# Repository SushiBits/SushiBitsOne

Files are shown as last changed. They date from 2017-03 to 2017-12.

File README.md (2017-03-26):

# SushiBits One

ARM Cortex-M in Arduino form factor, and consumes very little power.

## Introduction & Goal

This is one of my "design challenges" to myself:

*   Arduino-compatible form factor,
*   Take an 48-pin STM32 microcontroller (since STM32F103CBT6 are that cheap,)
*   Bring all I/O pins out somewhere, be it the connectors, JTAG or USB,
*   No two pins can be shorted together,
*   Use only switch-mode power supply,
*   Two layer PCB only,
*   Single side load.

## Main components

*   STM32 microcontroller in LQFP-48 package. I have tested the following:
    *   STM32F072C8T6 (Cortex-M0 @48MHz)
    *   STM32F103CBT6 (Cortex-M3 @72MHz)
    *   STM32L151CCT6 (Cortex-M3 @32MHz, ULP)
    *   STM32F303CCT6 (Cortex-M4F @72MHz)
    *   STM32F373CCT6 (Cortex-M4F @72MHz)
*   WCH CH340B: USB to UART adapter.
*   TI TPS562200: VIN to 5V buck converter.
*   TI LM3671-3.3: 5V to 3.3V buck converter.

## License

This is [open source hardware](http://www.oshwa.org/), licensed under the
[3-clause BSD license](LICENSE.md).

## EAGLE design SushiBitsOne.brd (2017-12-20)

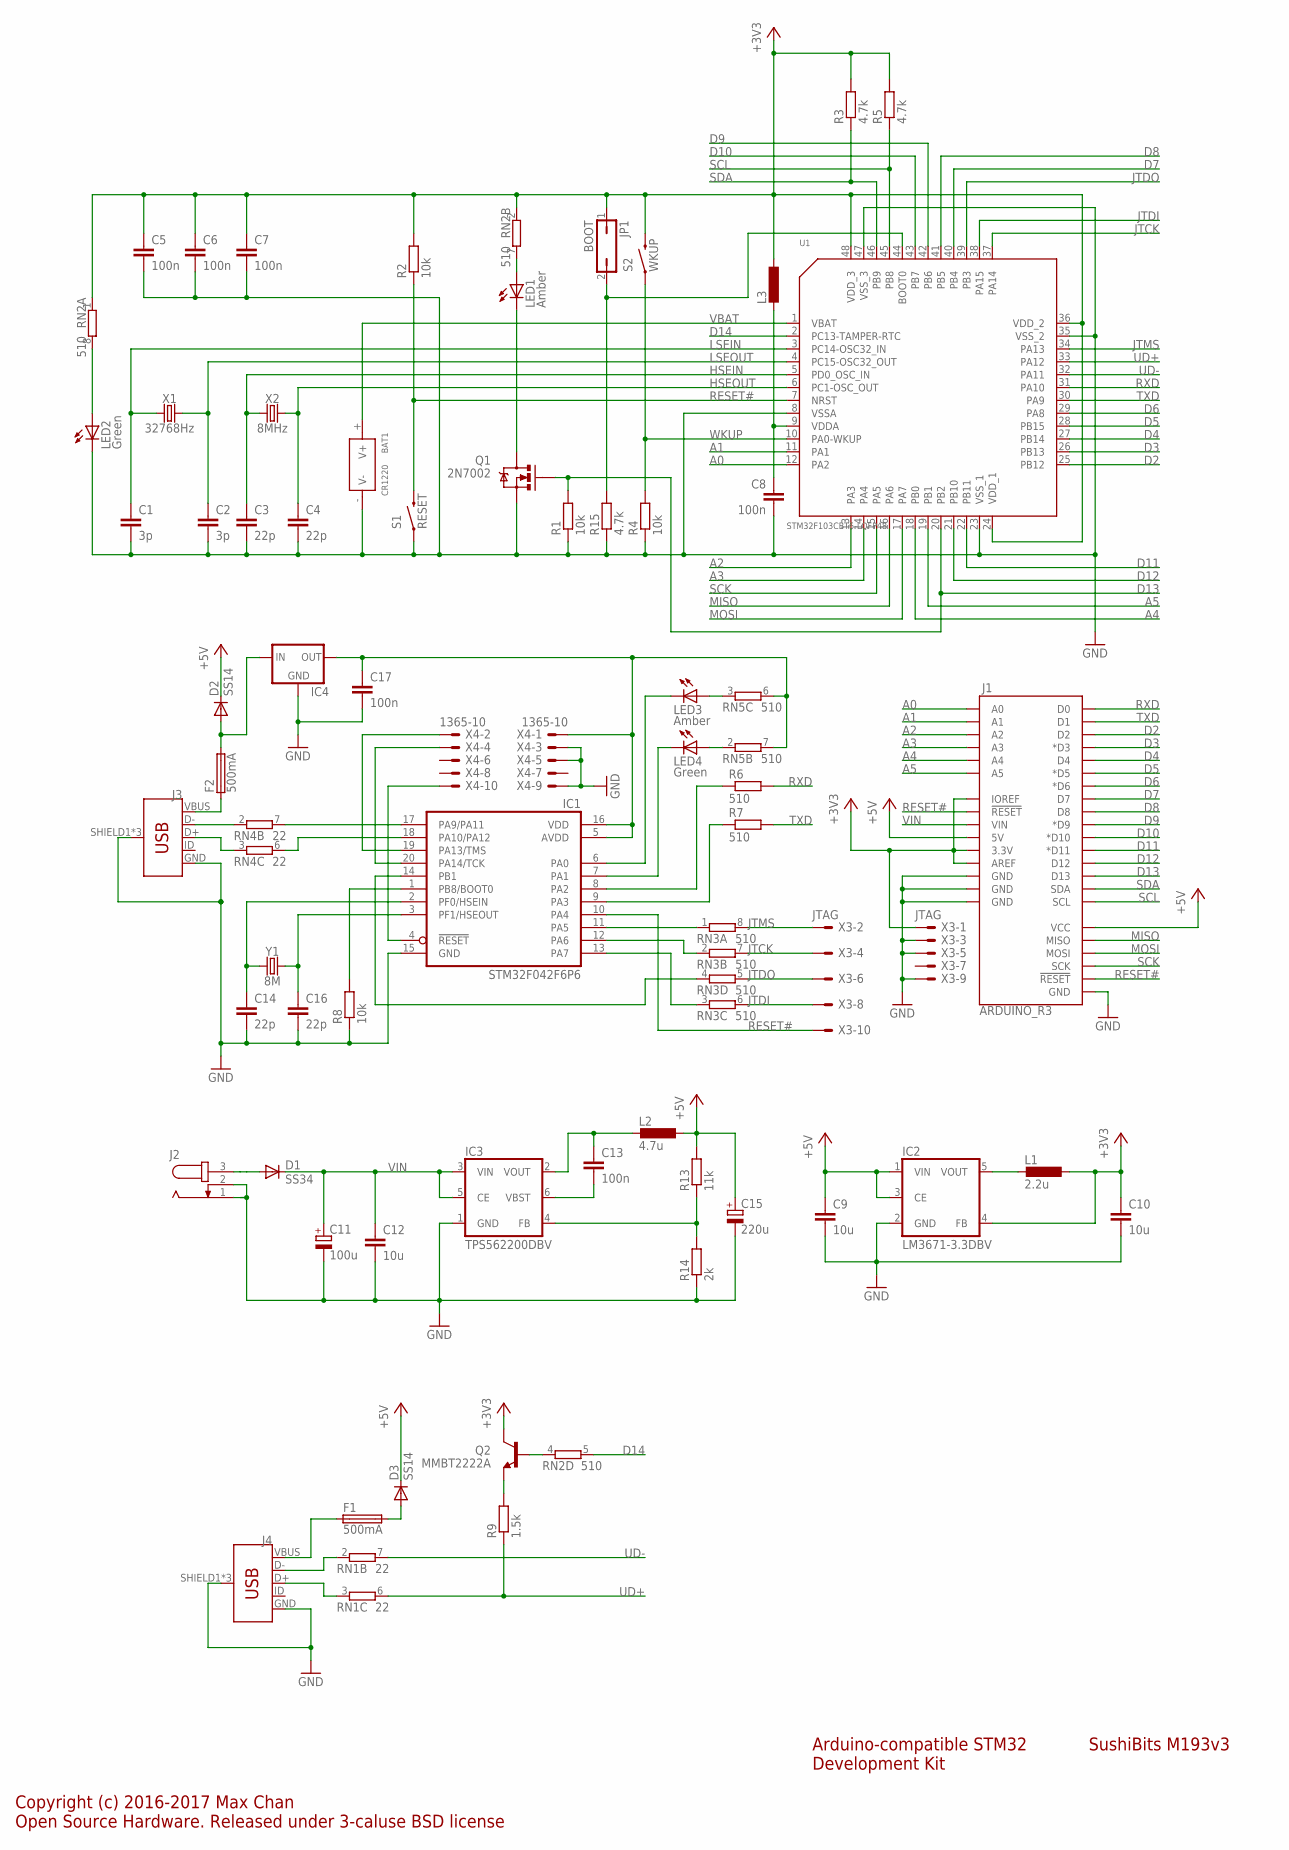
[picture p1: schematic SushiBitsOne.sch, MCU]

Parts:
BAT1: CR1220; BAT2P-SMD-16.4-CR1220
C1, C2: 3p; C0603
C3, C4, C14, C16: 22p; C0603
C5, C6, C7, C8, C13, C17: 100n; C0603
C9, C10, C12: 10u; C0805
C11: 100u; UD-8X10_NICHICON
C15: 220u; SMC_B
D1: SS34; DO214AC
D2, D3: SS14; SOD123
F1, F2: 500mA; R0805
IC1: STM32F042F6P6; TSSOP20
IC2: LM3671-3.3DBV; SOT23-5L
IC3: TPS562200DBV; SOT23-6L
IC4: XC63FPM; SOT23
J1: ARDUINO_R3
J2: JACK-PLUG0; SPC4077
J3, J4: USB_MICRO-B_FEMALE-SMT; USB-B-MICRO-SMD
JP1: BOOT; JP1
L1: 2.2u; L5650M
L2: 4.7u; L5650M
L3: L-EUL2012C; L2012C
LED1: Amber; CHIPLED_0805
LED2, LED4: Green; CHIP-LED0805
LED3: Amber; CHIP-LED0805
Q1: 2N7002; SOT23-3
Q2: MMBT2222A; SOT23-3
R1, R2, R4, R8: 10k; R0603
R3, R5, R15: 4.7k; R0603
R6, R7: 510; R0603
R9: 1.5k; R0603
R13: 11k; R0603
R14: 2k; R0603
RN1, RN4: 22; EXB38V
RN2, RN3, RN5: 510; EXB38V
S1: RESET; TACTILE-SWITCH-1101NE
S2: WKUP; TACTILE-SWITCH-1101NE
U1: STM32F103CBT6-LQFP48; LQFP48-0.5-7X7MM
X1: 32768Hz; CRYSTAL-SMD-3.2X1.5MM
X2: 8MHz; CRYSTAL-SMD-5X3.2-2PAD
X3: JTAG; 1365-10
X4: 1365-10
Y1: 8M; CRYSTAL-SMD-5X3.2-2PAD

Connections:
+3V3: C5.1, C6.1, C7.1, C10.1, IC2.4 (FB), J1.3.3V, J1.AREF, J1.IOREF, JP1.1, L1.1, L3.1, Q2.3 (C), R2.2, R3.2, R5.2, RN2.1, RN2.2 (1), S2.2, U1.24 (VDD_1), U1.36 (VDD_2), U1.48 (VDD_3), X3.1
+5V: C9.1, C15.+, D2.C, D3.C, IC2.1 (VIN), IC2.3 (CE), J1.5V, J1.VCC, L2.1, R13.2
A0: J1.A0, U1.12 (PA2)
A1: J1.A1, U1.11 (PA1)
A2: J1.A2, U1.13 (PA3)
A3: J1.A3, U1.14 (PA4)
A4: J1.A4, U1.18 (PB0)
A5: J1.A5, U1.19 (PB1)
D2: J1.D2, U1.25 (PB12)
D3: J1.D3 (*D3), U1.26 (PB13)
D4: J1.D4, U1.27 (PB14)
D5: J1.D5 (*D5), U1.28 (PB15)
D6: J1.D6 (*D6), U1.29 (PA8)
D7: J1.D7, U1.40 (PB4)
D8: J1.D8, U1.41 (PB5)
D9: J1.D9 (*D9), U1.42 (PB6)
D10: J1.D10 (*D10), U1.43 (PB7)
D11: J1.D11 (*D11), U1.22 (PB11)
D12: J1.D12, U1.21 (PB10)
D13: J1.D13, Q1.1 (G), R1.2, U1.20 (PB2)
D14: RN2.5 (2), U1.2 (PC13-TAMPER-RTC)
GND: BAT1.- (V-), C1.2, C2.2, C3.2, C4.2, C5.2, C6.2, C7.2, C8.2, C9.2, C10.2, C11.-, C12.2, C14.2, C15.-, C16.2, C17.2, IC1.15 (GND), IC2.2 (GND), IC3.1 (GND), IC4.1 (GND), J1.GND@1 (GND), J1.GND@2 (GND), J1.GND@3 (GND), J1.GND@4 (GND), J2.1, J2.2, J3.GND, J3.SHIELD1 (SHIELD), J3.SHIELD2 (SHIELD), J3.SHIELD3 (SHIELD), J4.GND, J4.SHIELD1 (SHIELD), J4.SHIELD2 (SHIELD), J4.SHIELD3 (SHIELD), LED2.C, Q1.2 (S), R1.1, R4.1, R8.1, R14.1, R15.1, S1.1, U1.8 (VSSA), U1.23 (VSS_1), U1.35 (VSS_2), U1.47 (VSS_3), X3.3, X3.5, X3.9, X4.3, X4.5, X4.9
HSEIN: C3.1, U1.5 (PD0_OSC_IN), X2.P$1 (1)
HSEOUT: C4.1, U1.6 (PC1-OSC_OUT), X2.P$2 (2)
JTCK: RN3.7 (2), U1.37 (PA14), X3.4
JTDI: RN3.6 (2), U1.38 (PA15), X3.8
JTDO: RN3.5 (2), U1.39 (PB3), X3.6
JTMS: RN3.8 (2), U1.34 (PA13), X3.2
LSEIN: C1.1, U1.3 (PC14-OSC32_IN), X1.P$1 (1)
LSEOUT: C2.1, U1.4 (PC15-OSC32_OUT), X1.P$2 (2)
MISO: J1.MISO, U1.16 (PA6)
MOSI: J1.MOSI, U1.17 (PA7)
unnamed: J4.D-, RN1.2 (1)
unnamed: J4.D+, RN1.3 (1)
unnamed: IC1.17 (PA9/PA11), RN4.7 (2)
unnamed: IC1.18 (PA10/PA12), RN4.6 (2)
unnamed: IC1.8 (PA2), R6.1
unnamed: IC1.9 (PA3), R7.1
unnamed: LED2.A, RN2.8 (2)
unnamed: LED1.C, Q1.3 (D)
unnamed: LED1.A, RN2.7 (2)
unnamed: IC2.5 (VOUT), L1.2
unnamed: D1.A, J2.3
unnamed: JP1.2, R15.2, U1.44 (BOOT0)
unnamed: D3.A, F1.2
unnamed: C13.1, IC3.2 (VOUT), L2.2
unnamed: C13.2, IC3.6 (VBST)
unnamed: D2.A, F2.2, IC4.3 (IN)
unnamed: IC3.4 (FB), R13.1, R14.2
unnamed: Q2.2 (E), R9.2
unnamed: Q2.1 (B), RN2.4 (1)
unnamed: C8.1, L3.2, U1.9 (VDDA)
unnamed: IC1.4 (!RESET), X4.10
unnamed: J3.D+, RN4.3 (1)
unnamed: J3.D-, RN4.2 (1)
unnamed: F2.1, J3.VBUS
unnamed: IC1.20 (PA14/TCK), X4.4
unnamed: IC1.19 (PA13/TMS), X4.2
unnamed: C17.1, IC1.5 (AVDD), IC1.16 (VDD), IC4.2 (OUT), RN5.6 (2), RN5.7 (2), X4.1
unnamed: C14.1, IC1.2 (PF0/HSEIN), Y1.P$1 (1)
unnamed: C16.1, IC1.3 (PF1/HSEOUT), Y1.P$2 (2)
unnamed: IC1.11 (PA5), RN3.1
unnamed: IC1.12 (PA6), RN3.2 (1)
unnamed: IC1.13 (PA7), RN3.3 (1)
unnamed: IC1.14 (PB1), RN3.4 (1)
unnamed: IC1.1 (PB8/BOOT0), R8.2
unnamed: IC1.6 (PA0), LED3.C
unnamed: IC1.7 (PA1), LED4.C
unnamed: LED4.A, RN5.2 (1)
unnamed: LED3.A, RN5.3 (1)
RESET#: IC1.10 (PA4), J1.RESET@1 (!RESET!), J1.RESET@2 (!RESET!), R2.1, S1.2, U1.7 (NRST), X3.10
RXD: J1.D0, R6.2, U1.31 (PA10)
SCK: J1.SCK, U1.15 (PA5)
SCL: J1.SCL, R5.1, U1.45 (PB8)
SDA: J1.SDA, R3.1, U1.46 (PB9)
TXD: J1.D1, R7.2, U1.30 (PA9)
UD+: R9.1, RN1.6 (2), U1.33 (PA12)
UD-: RN1.7 (2), U1.32 (PA11)
VBAT: BAT1.+ (V+), U1.1 (VBAT)
VBUS2: F1.1, J4.VBUS
VIN: C11.+, C12.1, D1.C, IC3.3 (VIN), IC3.5 (CE), J1.VIN
WKUP: R4.2, S2.1, U1.10 (PA0-WKUP)

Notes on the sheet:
Arduino-compatible STM32 Development Kit
SushiBits M193v3
Copyright (c) 2016-2017 Max Chan Open Source Hardware. Released under 3-caluse BSD license

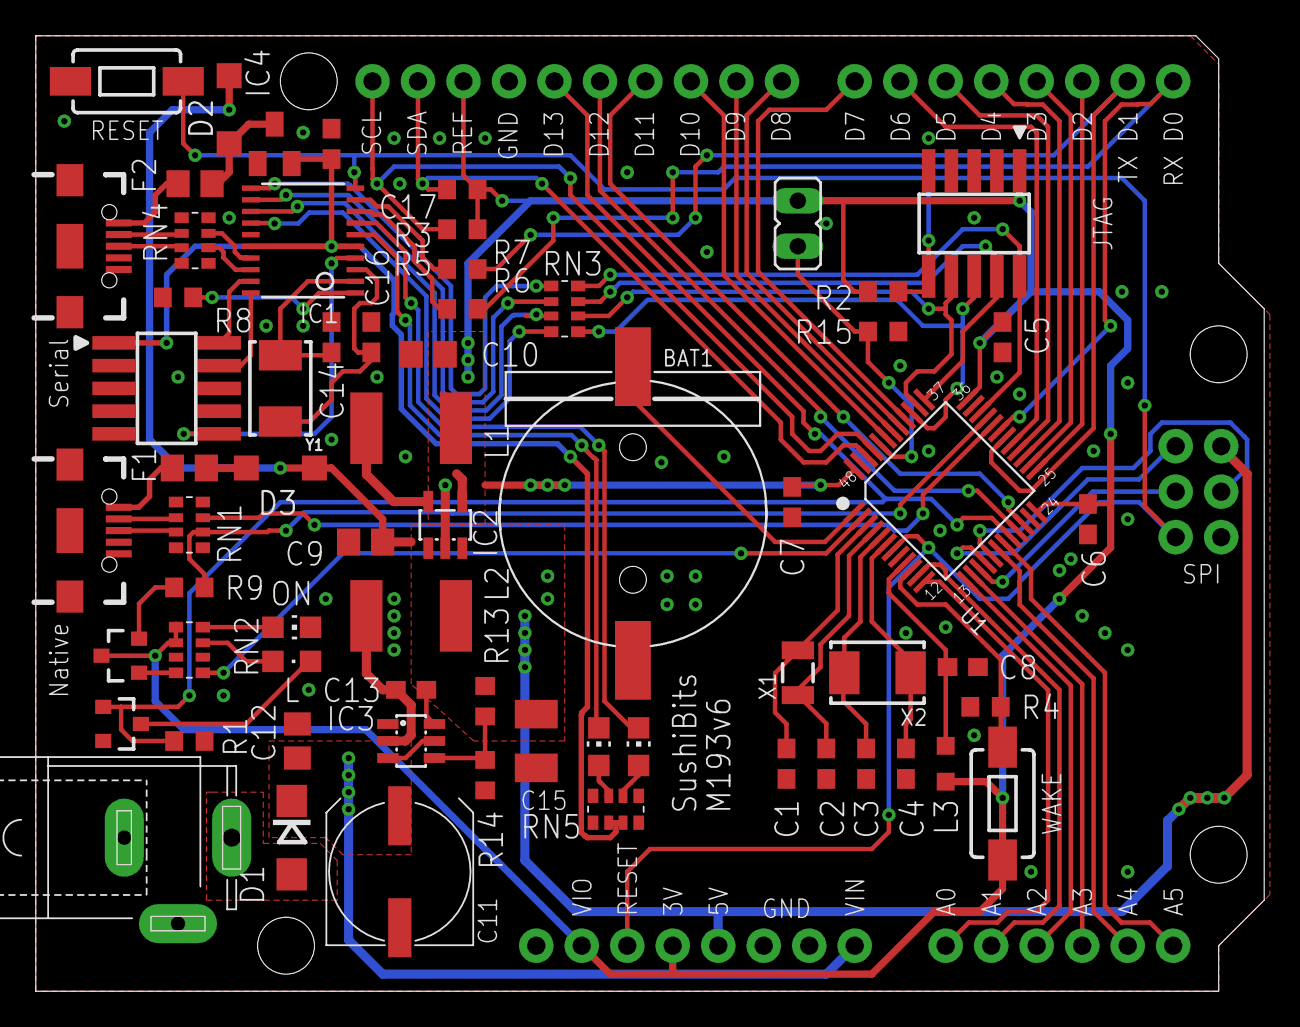
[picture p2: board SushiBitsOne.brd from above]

Board: 2 copper layers, 68.6 x 53.3 mm, 66 parts (0 on the bottom side), 82 nets.

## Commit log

2017-03-23 Initial Commit for completed project
    [SushiBitsOne.brd, SushiBitsOne.sch]
2017-08-19 Release: M193v3
    [SushiBitsOne.brd, SushiBitsOne.sch]
2017-11-02 Adjusting for the v4
    [SushiBitsOne.brd, SushiBitsOne.sch]
2017-11-02 Implemented the USB microcontroller with USB-Serial and CMSIS-DAP.
    [SushiBitsOne.brd, SushiBitsOne.sch]
2017-11-02 Releasing M193v4
    [SushiBitsOne.sch]
2017-11-02 Preparing v3.1 release.
    [SushiBitsOne.brd]
2017-11-02 Missed a spot check on board silkscreen
    [SushiBitsOne.brd]
2017-11-03 There is a net overlap.
    [SushiBitsOne.brd]
2017-12-04 Relayout the board to accomodate component changes.
    [SushiBitsOne.brd, SushiBitsOne.sch]
2017-12-04 Change up some footprints.
    [SushiBitsOne.brd, SushiBitsOne.sch]
2017-12-20 Some manufacturability and cleanup work
    [SushiBitsOne.brd, SushiBitsOne.sch]
2017-12-20 Squeezed the onboard debugger back in.
    [SushiBitsOne.brd, SushiBitsOne.sch]
2017-12-20 Some details of the files are somehow changed?
    [SushiBitsOne.brd, SushiBitsOne.sch]
2017-12-20 Adding the pin indicator back on DAP42
    [SushiBitsOne.brd]
2017-12-21 I missed the version number on the PDF file
    [SushiBitsOne.sch]

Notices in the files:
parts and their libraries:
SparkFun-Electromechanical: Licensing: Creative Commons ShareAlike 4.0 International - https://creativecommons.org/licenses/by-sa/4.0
